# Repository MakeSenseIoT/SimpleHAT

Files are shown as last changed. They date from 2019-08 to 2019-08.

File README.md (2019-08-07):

## MakeSenseIoT SimpleHAT

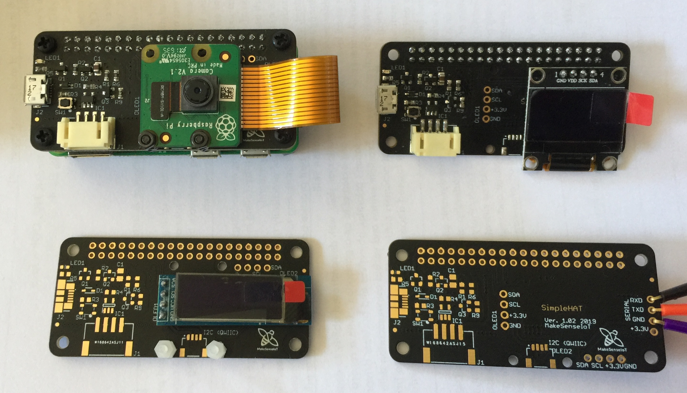
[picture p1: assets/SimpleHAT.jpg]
<br/>

PCB files for the SimpleHAT by MakeSenseIoT  

Format is EagleCAD schematic and board layout

### Hardware

The SimpleHAT is a Raspberry Pi Zero W HAT with multiple functionalities. 
It can operate as a standalone unit or as a part of more complex system, for example
Solar Powered IoT camera. 
The SimpleHAT hardware includes:

* Circutry for powering ON/OFF Raspberry Pi using external signal 
* Placeholder for Raspberry Pi Camera module
* Placeholder for 0.91" OLED display module
* Placeholder for 1.3" OLED display module
* Placeholder for UART to USB converter
* Placeholder for I2C (QWIIC)

Note: Due to physical limitation, not all hardware options can be used togrther

### RPI Software
* ON/OFF

For ON/OFF functionality use Pimoroni one-line installer for daemon configuration:

```
curl https://get.pimoroni.com/onoffshim | bash
```
 **IMPORTANT** Do not use pushbutton while using external signal for ON/OF
as it might result in damaging of external driving circuitry. There is no protecting
circuit to prevent it. Use only one ON/OFF source at a time.

* I2C OLEDs
There are multiple online tutorials and example code available online 

* Raspberry Pi Camera UV4L 
There are multiple online tutorials and example code available online. We use UV4L - for installation details
see [UV4L](https://www.linux-projects.org/uv4l/installation/)

## Authors

* **Jan Szymanski** - *Initial work* - [MakeSenseIoT](http://www.makesenseiot.com)

## Acknowledgments

* The OnOff SHIM code by Pimoroni is used
* Inspired by Pimoroni project updated and modified [Pimoroni](https://shop.pimoroni.com/products/onoff-shim)

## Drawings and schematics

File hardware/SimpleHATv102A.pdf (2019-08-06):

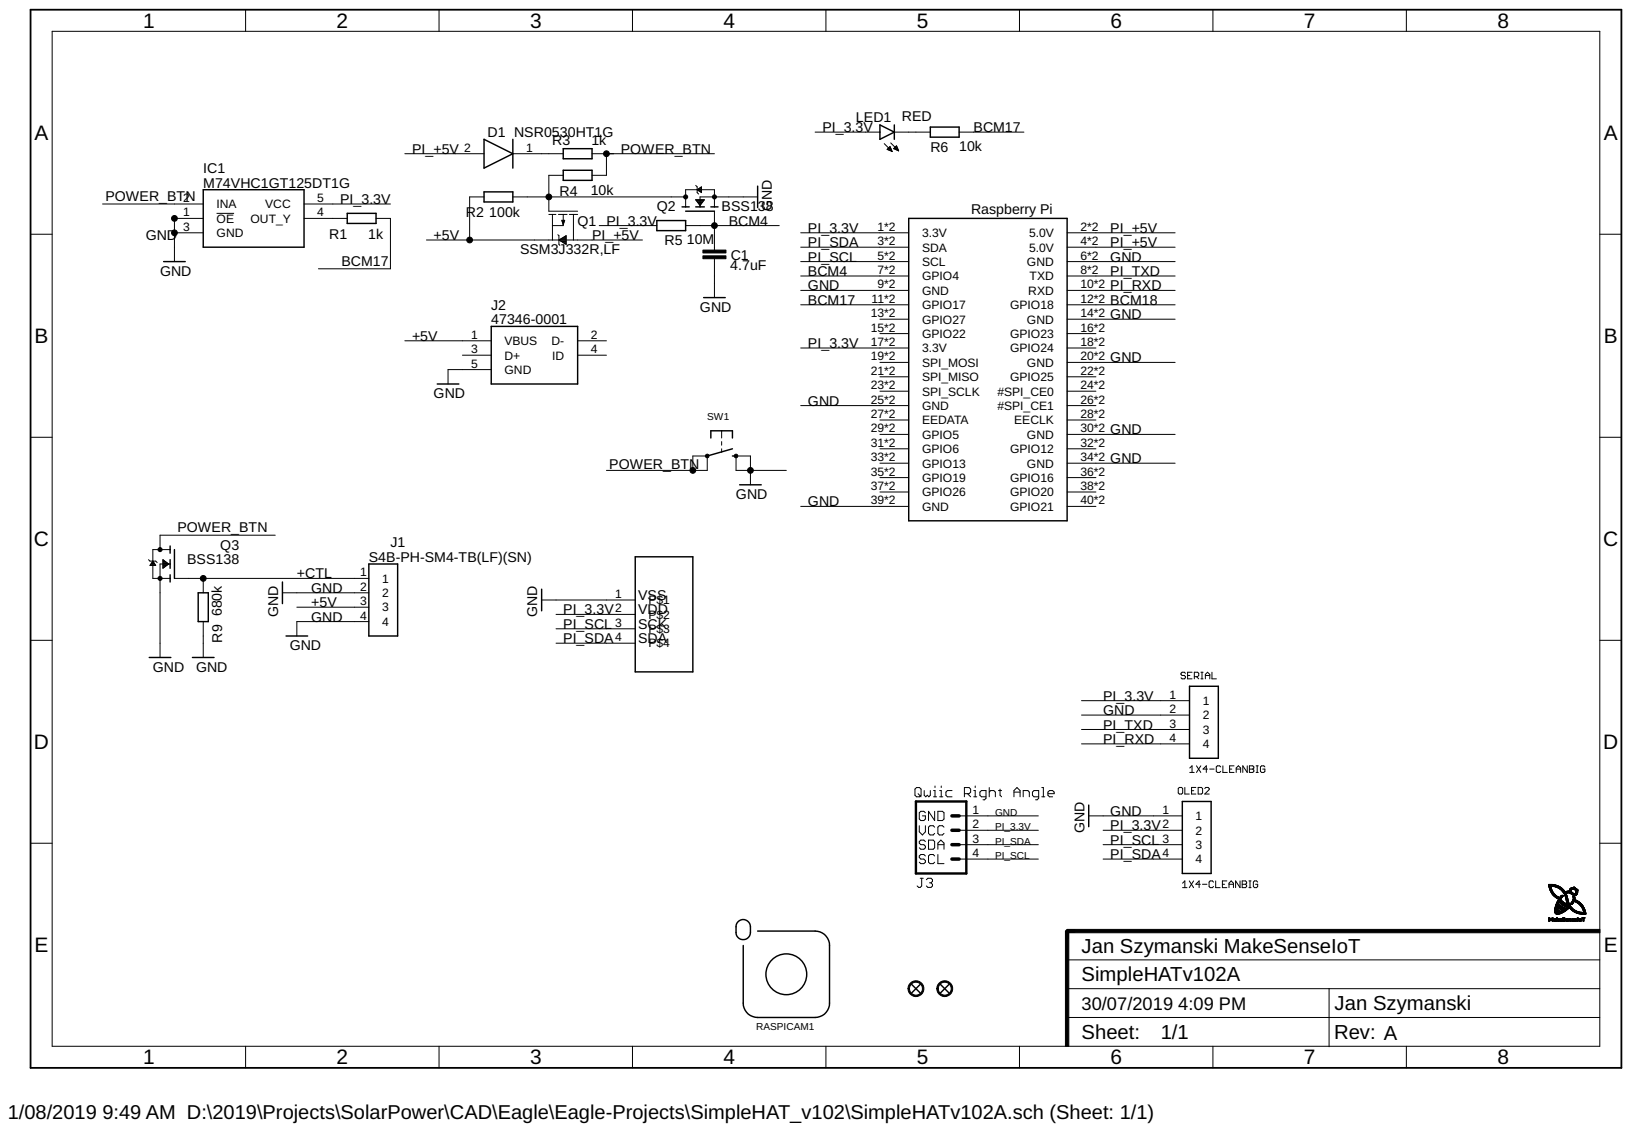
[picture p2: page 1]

30/07/2019 4:09 PM | Jan Szymanski
Sheet: 1/1 | Rev: A

1/08/2019 9:49 AM D:\2019\Projects\SolarPower\CAD\Eagle\Eagle-Projects\SimpleHAT_v102\SimpleHATv102A.sch (Sheet: 1/1)

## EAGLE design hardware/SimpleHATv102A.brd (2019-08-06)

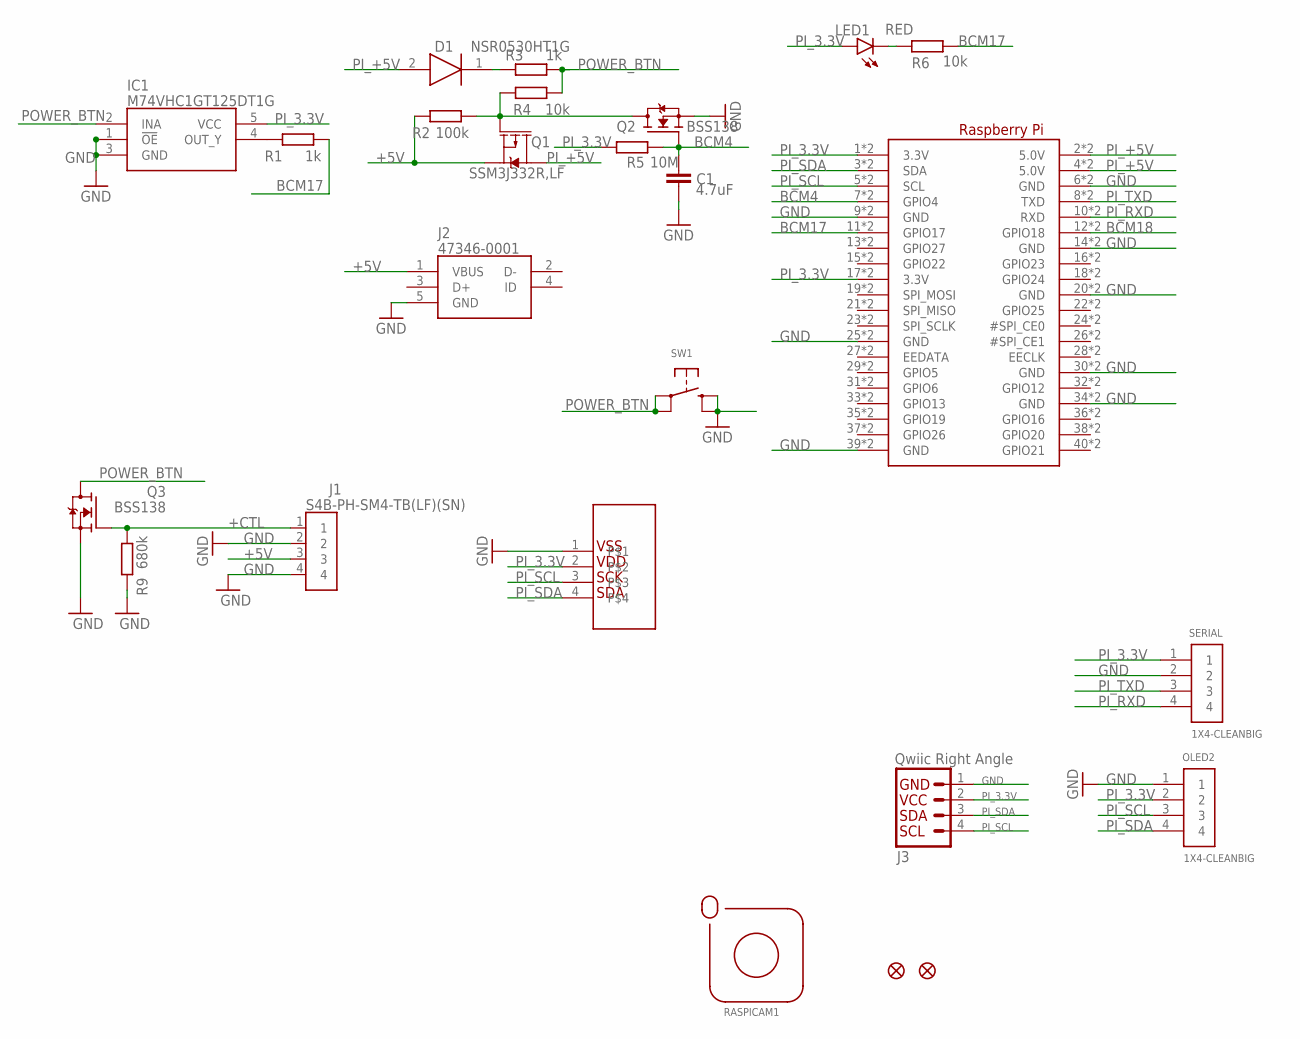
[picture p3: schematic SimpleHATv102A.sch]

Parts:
C1: 4.7uF; C0805K
D1: NSR0530HT1G; SOD2512X110N
FD1, FD2: SPARKFUN-AESTHETICS_FIDUCIAL1X2; SPARKFUN-AESTHETICS_FIDUCIAL-1X2
IC1: M74VHC1GT125DT1G; SOT95P275X110-5N
J1: S4B-PH-SM4-TB(LF)(SN); S4B-PH-SM4-TB
J2: 47346-0001
J3: Qwiic Right Angle; SPARKFUN-CONNECTORS_JST04_1MM_RA
LED1: RED; CHIP-LED0603
OLED1: 128X32OLEDMODULE0.96"MODULEPCB; 128X32OLED
OLED2: 1X4-CLEANBIG; 1X04-CLEANBIG
Q1: SSM3J332R,LF; SOT23-3
Q2, Q3: BSS138; SOT23
R1, R3: 1k; R0603
R2: 100k; R0603
R4, R6: 10k; R0603
R5: 10M; R0603
R9: 680k; R0603
RASPICAM1: RASPICAM
RPI1: ADAFRUIT-LORA-RADIO-BONNET-WITH-OLED_MICROBUILDER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; ADAFRUIT-LORA-RADIO-BONNET-WITH-OLED_MICROBUILDER_PI_BONNET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
SERIAL: 1X4-CLEANBIG; 1X04-CLEANBIG
SW1: MICROBUILDER_SWITCH_TACT_SMTKMT0; MICROBUILDER_BTN_KMT0

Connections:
+5V: J1.3, J2.1 (VBUS), Q1.2 (S), R2.2
+CTL: J1.1, Q3.1 (G), R9.1
BCM4: C1.2, Q2.1 (G), R5.1, RPI1.7 (GPIO4), RPI1.S7 (GPIO4)
BCM17: R1.1, R6.2, RPI1.11 (GPIO17), RPI1.S11 (GPIO17)
BCM18: RPI1.12 (GPIO18), RPI1.S12 (GPIO18)
GND: C1.1, IC1.1 (!OE), IC1.3 (GND), J1.2, J1.4, J2.5 (GND), J3.1, OLED1.1, OLED2.1, Q2.2 (S), Q3.2 (S), R9.2, RPI1.6 (GND), RPI1.9 (GND), RPI1.14 (GND), RPI1.20 (GND), RPI1.25 (GND), RPI1.30 (GND), RPI1.34 (GND), RPI1.39 (GND), RPI1.S6 (GND), RPI1.S9 (GND), RPI1.S14 (GND), RPI1.S20 (GND), RPI1.S25 (GND), RPI1.S30 (GND), RPI1.S34 (GND), RPI1.S39 (GND), SERIAL.2, SW1.B (S), SW1.B' (S1)
unnamed: IC1.4 (OUT_Y), R1.2
unnamed: LED1.C, R6.1
unnamed: D1.1 (K), R3.2
unnamed: Q1.1 (G), Q2.3 (D), R2.1, R4.2
PI_3.3V: IC1.5 (VCC), J3.2, LED1.A, OLED1.2, OLED2.2, R5.2, RPI1.1 (3.3V), RPI1.17 (3.3V), RPI1.S1 (3.3V), RPI1.S17 (3.3V), SERIAL.1
PI_+5V: D1.2 (A), Q1.3 (D), RPI1.2 (5.0V), RPI1.4 (5.0V), RPI1.S2 (5.0V), RPI1.S4 (5.0V)
PI_RXD: RPI1.10 (RXD), RPI1.S10 (RXD), SERIAL.4
PI_SCL: J3.4, OLED1.3, OLED2.3, RPI1.5 (SCL), RPI1.S5 (SCL)
PI_SDA: J3.3, OLED1.4, OLED2.4, RPI1.3 (SDA), RPI1.S3 (SDA)
PI_TXD: RPI1.8 (TXD), RPI1.S8 (TXD), SERIAL.3
POWER_BTN: IC1.2 (INA), Q3.3 (D), R3.1, R4.1, SW1.A, SW1.A' (P1)

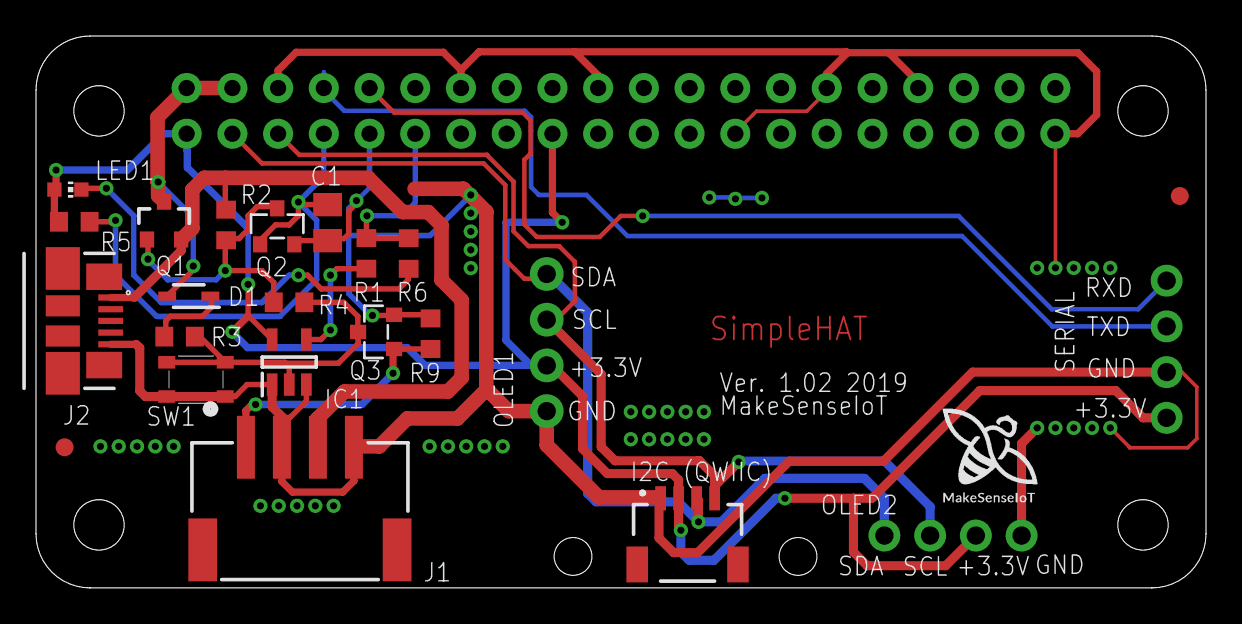
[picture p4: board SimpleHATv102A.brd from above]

Board: 2 copper layers, 65.0 x 30.7 mm, 25 parts (0 on the bottom side), 17 nets.
